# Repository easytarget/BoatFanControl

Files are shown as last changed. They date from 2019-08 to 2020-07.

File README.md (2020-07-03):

# Humidity and Temperature sensing fan controller for a small boat, with battery protector.
## By Owen.
#### My boat can get quite hot, suffers from condensation, and a permanent fan kept on flattening the battery.

A Small controller based on a Digispark ATTiny85 development board I have lying around and a spare DHT11 combined temperature and humidity sensor.
It turns the ventilator fan on and off (and several speeds in between) depending on the temperature, humidity, user input and battery state (voltage).

* [DigiSpark](https://digistump.com/wiki/digispark) Based
  * ATtiny85, plenty powerful enough for this application, and with a robust toolchain. It has 6 IO pins & very little extra cruft
  * Has a onboard 5v regulator, I can supply it with the battery voltage, and then power the DHT11 from the 5v line
  * Somewhat tricky to flash/develop for, Lack of a uart is a total pain during debug since BitBang serial emulators eat half the memory+
* DHT11 Temperature and Humidity sensor
  * Not the best sensor, something more accurate would be prefered, but this is what I have
  * A DHT22 would be an easy (plug and go) upgrade
* PWM fan control via a high-current logic-level NPN mosfet
  * I have a quiet but powerful (Noctuna) 12V PC case fan to run from this
* Battery voltage sensing for powersave and shutdown. My boat has a good battery and solar charging system, but the battery can still get low during use and late season.
* A button.. to allow on/off/quiet overrides, my bunk is 50cm from the fan and a quiet mode seems like a really good idea.

## Hardware
KiKad project files, Gerber files and the Case design files are all in this repository.

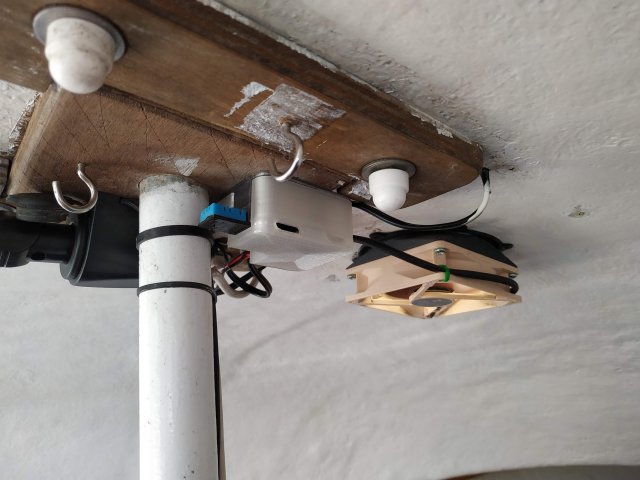
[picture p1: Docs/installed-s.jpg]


The circuit is very simple, there is a logic-level mosfet to drive the fan. I used a IRLZ14 for this but almost any logic-level mosfet will do, just make sure it can handle the *startup* current of your fan. If your fan is powerful you may need to add a heatsink to the mosfet and make sure heat from it does not affect the sensor.

The Digispark incorporates a 5V voltage regulator (LM7805), which only powers the ATTiny and the DHT11 sensor, the absolute maximum voltage this can handle is 35V, Digistump themselves recommend a maximum of 16V for the module. Please be careful when disconnecting batteries on boarts with solar/fixed charging systems, you may be able to spike the supply voltage enough to damage this. However; it is reasonably robust and may even work for a 24v systems, but no promises, and you will need to change the thresholds in the code ;-)

Here are some picture of my buildup; at this stage I had, *ahem*, forgotten to put a flyback diode in parallel to the fan. This could be a very bad idea if a high wind decides to spin the fan very fast. It is not visible in my pictures but I added a 1N4007 diode to the underside between the pins of the connector. The revised PCB now has this flyback diode onboard.

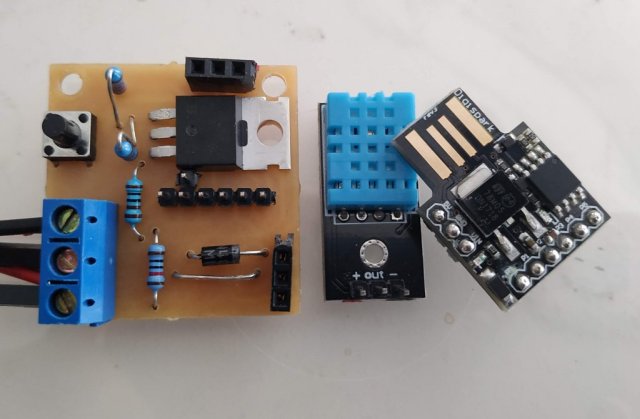
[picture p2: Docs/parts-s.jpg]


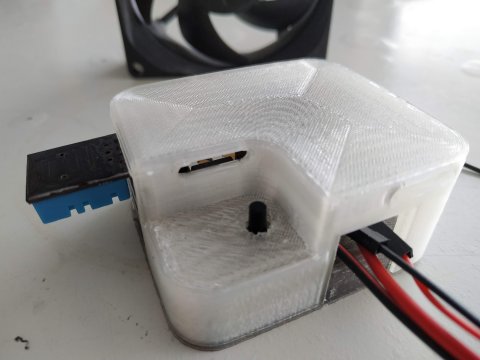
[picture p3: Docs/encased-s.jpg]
Ready To Fit
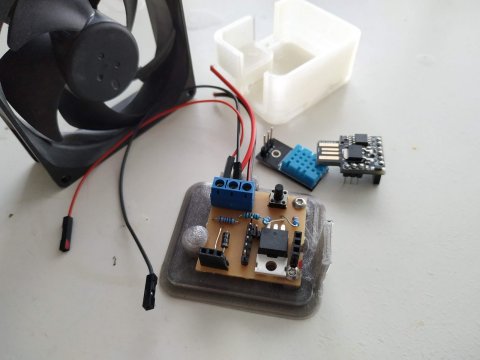
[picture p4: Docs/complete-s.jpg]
Proud
 

## Software
See the `BoatFanControl.ino` sketch in the `Software` folder. There are a number of other sketches in there that I used during development, you may find the `*Calibrate` scripts useful to verify your sensors and voltage divider.

The DigiStump boards definitions are [here](http://digistump.com/package_digistump_index.json), this needs to be added to the Boards URL list in the preferences dialog of the IDE. In the IDE, select `baoards -> Digistump AVR boards -> Digispark (16MHz, no USB)` for programming. The 'No USB' refers to clock speed alignment and is advised to keep the clock stable when not plugged into a USB port.

Please read the notes at the top of the main sketch, by default the Digispark runs the fan at 500Hz, this is possibly audible and might affect fan lifespan (the jury is out, I've seen people arguing both sides quite convincingly). In any case I decided to pump the [fan PWM frequency](https://digistump.com/wiki/digispark/tricks#how_to_increase_hardware_pwm_frequency) up as high as possible. But this requires modifying a file in the Digispark boards folder, proper details and URL's for reference are in the sketch header.

## Operation

* The controller takes a Temperature and Humidity reading every 20 seconds and then decides how to set fan based on the readings over the last 2 minutes.
* Power Control; the controller also reads the battery voltage and uses this to reduce battery drain when needed.
  * Vmin->11.8V : Powersave; no activity, but still wake every 20s to take and process a voltage reading. 
  * 11.8->12.5V : Low Power; fan is restricted to 33% power.
  * 12.5->Vmax  : Good Power; fan can rise to 100% power.
* Fan Control
  * The fan works on simple trigger values for temperature and humidity (28c and 70% respectively), the fan will start at 33% PWM power, and rise to 100% over the next four degrees temperature or 20% humidity. In low power mode the speed will never rise and remains at 30%
* Average readings; the last five readings are kept, the code discards any outliers before averaging the three middle values. This reduces any fast cycling and ignores the occasional 'way off' reading that DHT11's can occasionally produce (in my experience).
* User Control
  * The Button cycles: Full -> Quiet -> Off -> Full etc.. and the led flashes for feedback; two flashes for off, four for quiet and six for full.
  * Quiet mode is basically the same as Low power mode.
  * After three hours the User mode will change to the next higher power level, so that the button works more like a 3 hour 'sleep' function, it is not a on/off switch. I have an independently fused and switched line from my battery for this, and the mast head anchor light.
* The onboard LED flashes to indicate mode changes, errors, and when a sensor reading is made. It is dimmed in Quiet and Off modes.
  * If the unit continually flashes after startup then it is indicating a sensor disconnect or failure. 
  * During operation 10 very rapid flashes indicate a failed sensor reading.
* Testing is tricky due to lack of resources, serial debug is not practical due to memory and pin limitations. I found it best to test the sensors using the calibrate sketches. Then I ran on the testbench with much 'faster' timeouts (there is a option for this in the sketch), and my multimeters PWM (cycle and frequency) mode to check the output. I also used an identical sensor running on a Arduino Uno + a standard serial output DHT11 example to monitor the environment, and then spent time checking the results while breathing on sensors to trigger responses, and varying the voltage on my PSU.

## Low Power
If the battery is good and the fan is running then the power use is dominated by the fan (the mosfet is good to 6A).

But once the voltage drops to powersave levels it is desirable to have the controller draw minimal power to avoid flooring the battery.
* I use a low-power sleep mode between readings when the fan is off, this should reduce the load from the DigiSpark from a few milliamps to a few microamps. I dont have a meter sensitive enough to measure this with any accuracy.
* If you are serious about reducing power I also suggest replacing the R1/R2 (10K/1K) divider used for voltage sensing with a 470K/47K one, this reduces the power flow through them from 1.1 milliamps to 23 microamps at 12v.
* The DHT11 draws up to 2.5 milliamp when doing a reading and sending data, but should be under 100 microamps between readings. If I do a MK2 pcb I will power the DHT11 from the unused D4 pin (the ATtiny can supply enough power for this) and modify the code to switch it off between readings (nb: 250ms needed to recover when powered on).

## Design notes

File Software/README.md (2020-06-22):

# Code for the boat Fan Controller
Primary/complete code is in 'BoatFanControl' folder, please read the comments

The 'VoltageCalibrate' and 'SensorCalibrate' sketches are useful for verifying the hardware as well as checking calibration

Other folders contain test and/or experimental code I have played with

All code is for the DigiSpark board, ATTiny 85 based, and assumes the Arduino IDE is used

The tiny DHT11 sensor lib I use is from:
http://www.micro4you.com/files/sensor/
The files are included in the archive

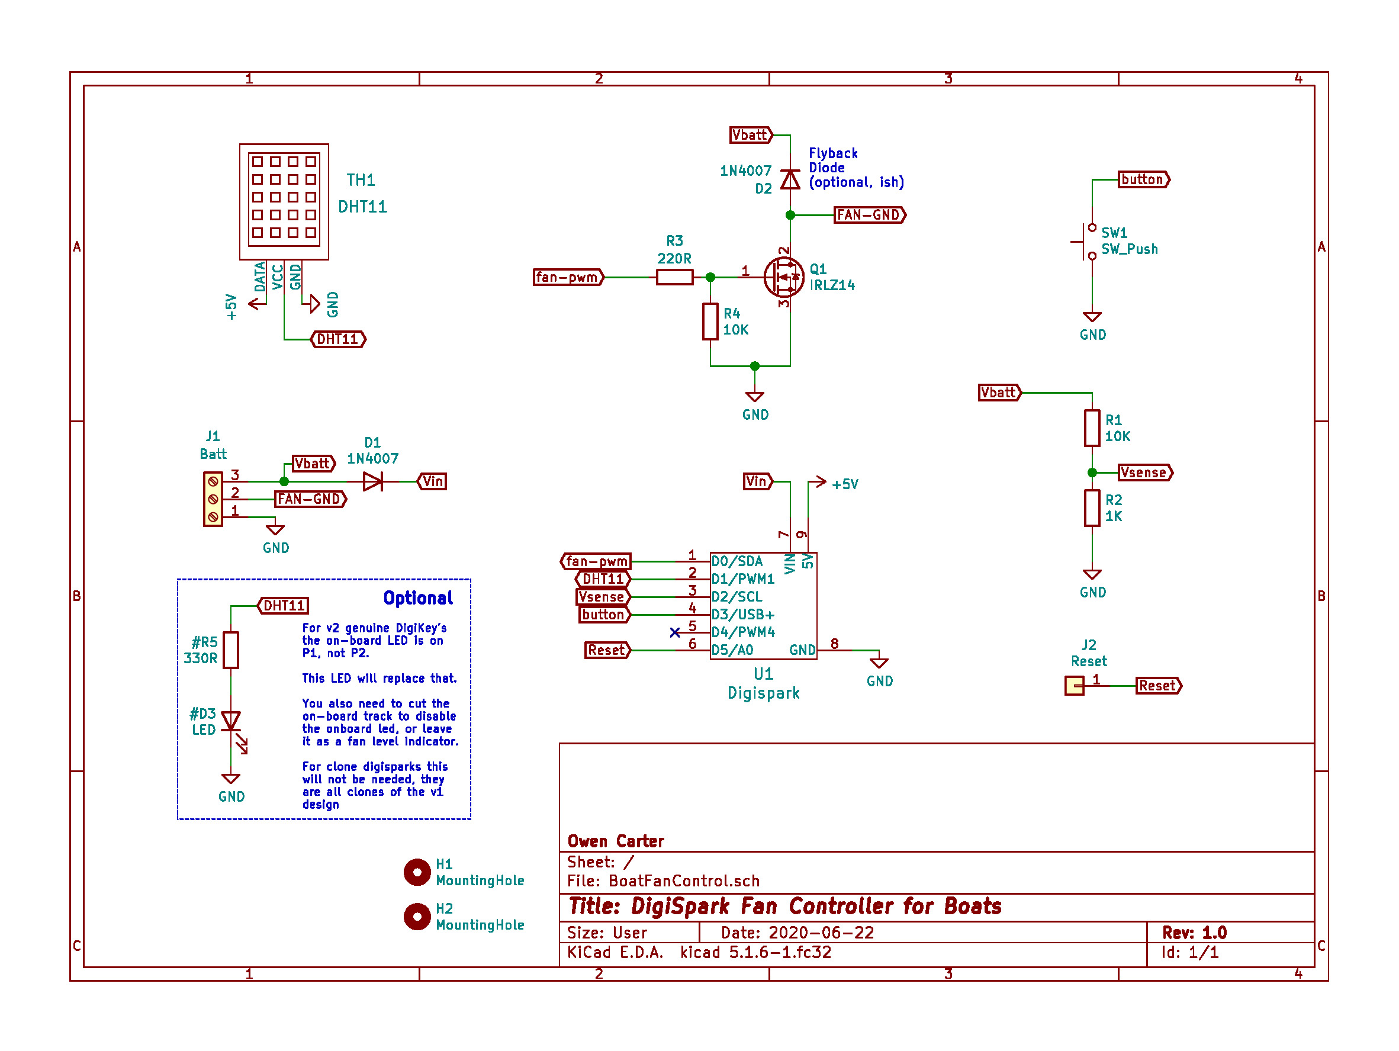
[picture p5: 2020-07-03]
Docs/Schematic.jpg

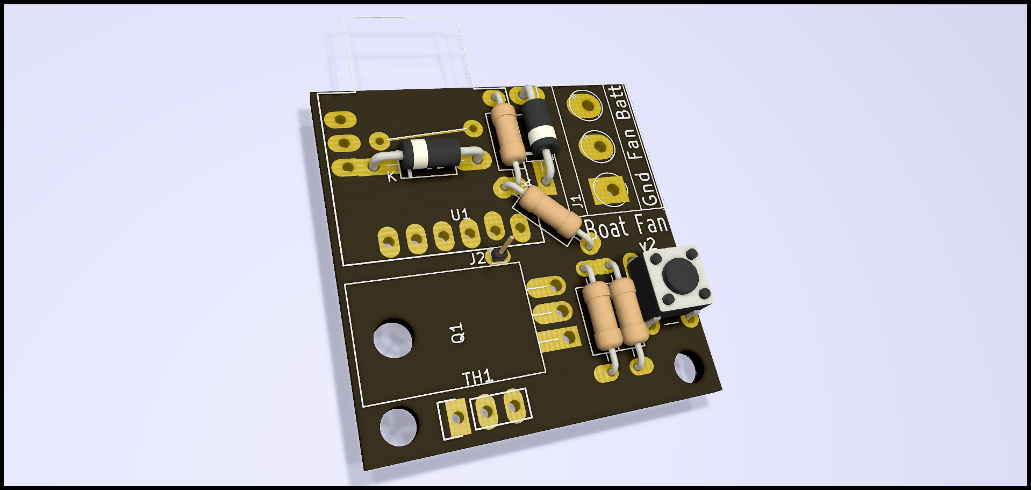
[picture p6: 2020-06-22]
Docs/BoatFanControlPCB.png

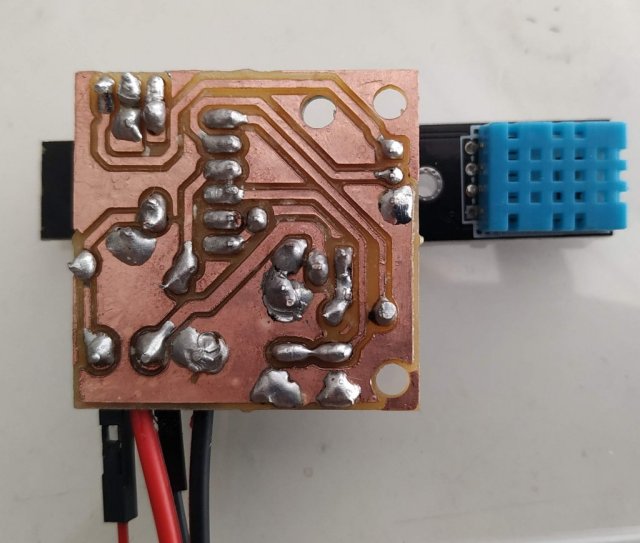
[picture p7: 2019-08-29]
Docs/pcb-s.jpg

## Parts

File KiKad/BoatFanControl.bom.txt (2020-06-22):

"Source:","/home/owen/Circuits/BoatFanControl/KiKad/BoatFanControl.sch"
"Date:","Mon 22 Jun 2020 17:11:08 CEST"
"Tool:","Eeschema 5.1.6-1.fc32"
"Generator:","/usr/share/kicad/plugins/bom_csv_grouped_by_value.py"
"Component Count:","14"

"Individual Components:"

"Item","Qty","Reference(s)","Value","LibPart","Footprint","Datasheet","Description","Manufacturer","Pricing"
"","","D1","1N4007","Diode:1N4007","Diode_THT:D_DO-41_SOD81_P10.16mm_Horizontal","http://www.vishay.com/docs/88503/1n4001.pdf","","",""
"","","D2","1N4007","Diode:1N4007","Diode_THT:D_DO-41_SOD81_P10.16mm_Horizontal","http://www.vishay.com/docs/88503/1n4001.pdf","","",""
"","","H1","MountingHole","Mechanical:MountingHole","MountingHole:MountingHole_3.2mm_M3","~","","",""
"","","H2","MountingHole","Mechanical:MountingHole","MountingHole:MountingHole_3.2mm_M3","~","","",""
"","","J1","Batt","Connector:Screw_Terminal_01x03","TerminalBlock_MetzConnect:TerminalBlock_MetzConnect_Type073_RT02603HBLU_1x03_P5.08mm_Horizontal","~","","",""
"","","J2","Reset","Connector_Generic:Conn_01x01","Connector_PinHeader_1.00mm:PinHeader_1x01_P1.00mm_Vertical","~","","",""
"","","Q1","IRLZ14","Transistor_FET:IRLIZ44N","Package_TO_SOT_THT:TO-220F-3_Horizontal_TabDown","http://www.irf.com/product-info/datasheets/data/irliz44n.pdf","","",""
"","","R1","10K","Device:R","Resistor_THT:R_Axial_DIN0207_L6.3mm_D2.5mm_P10.16mm_Horizontal","~","","",""
"","","R2","1K","Device:R","Resistor_THT:R_Axial_DIN0207_L6.3mm_D2.5mm_P10.16mm_Horizontal","~","","",""
"","","R3","220R","Device:R","Resistor_THT:R_Axial_DIN0207_L6.3mm_D2.5mm_P10.16mm_Horizontal","~","","",""
"","","R4","10K","Device:R","Resistor_THT:R_Axial_DIN0207_L6.3mm_D2.5mm_P10.16mm_Horizontal","~","","",""
"","","SW1","SW_Push","Switch:SW_Push","Button_Switch_THT:SW_PUSH_6mm","~","","",""
"","","TH1","DHT11","sensorz:DHT11_Temperature_Humidity","sensorz:DHT11_Temperature_Humidity","","","",""
"","","U1","Digispark","mcuz:Digispark","mcuz:Digispark","","Digispark Microcontroller","Digistump","0.00@0"

"Collated Components:"

"Item","Qty","Reference(s)","Value","LibPart","Footprint","Datasheet","Description","Manufacturer","Pricing"
"1","2","D1, D2","1N4007","Diode:1N4007","Diode_THT:D_DO-41_SOD81_P10.16mm_Horizontal","http://www.vishay.com/docs/88503/1n4001.pdf","","",""
"2","2","H1, H2","MountingHole","Mechanical:MountingHole","MountingHole:MountingHole_3.2mm_M3","~","","",""
"3","1","J1","Batt","Connector:Screw_Terminal_01x03","TerminalBlock_MetzConnect:TerminalBlock_MetzConnect_Type073_RT02603HBLU_1x03_P5.08mm_Horizontal","~","","",""
"4","1","J2","Reset","Connector_Generic:Conn_01x01","Connector_PinHeader_1.00mm:PinHeader_1x01_P1.00mm_Vertical","~","","",""
"5","1","Q1","IRLZ14","Transistor_FET:IRLIZ44N","Package_TO_SOT_THT:TO-220F-3_Horizontal_TabDown","http://www.irf.com/product-info/datasheets/data/irliz44n.pdf","","",""
"6","2","R1, R4","10K","Device:R","Resistor_THT:R_Axial_DIN0207_L6.3mm_D2.5mm_P10.16mm_Horizontal","~","","",""
"7","1","R2","1K","Device:R","Resistor_THT:R_Axial_DIN0207_L6.3mm_D2.5mm_P10.16mm_Horizontal","~","","",""
"8","1","R3","220R","Device:R","Resistor_THT:R_Axial_DIN0207_L6.3mm_D2.5mm_P10.16mm_Horizontal","~","","",""
"9","1","SW1","SW_Push","Switch:SW_Push","Button_Switch_THT:SW_PUSH_6mm","~","","",""
"10","1","TH1","DHT11","sensorz:DHT11_Temperature_Humidity","sensorz:DHT11_Temperature_Humidity","","","",""
"11","1","U1","Digispark","mcuz:Digispark","mcuz:Digispark","","Digispark Microcontroller","Digistump","0.00@0"

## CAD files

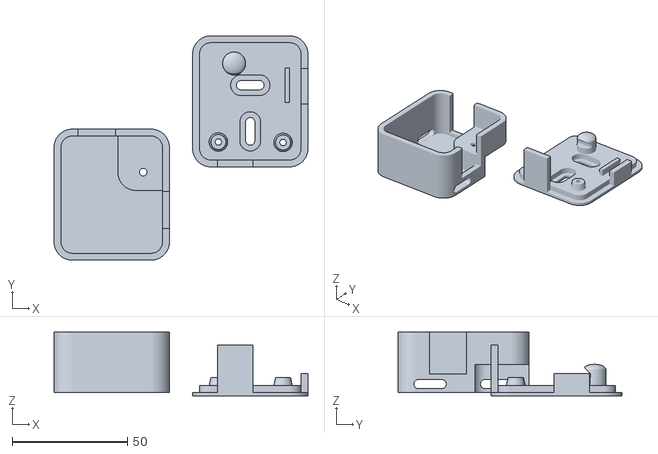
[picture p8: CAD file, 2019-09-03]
Case/case.stl
110.0 x 97.2 x 27.6

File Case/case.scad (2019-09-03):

// Case for Boat fan Controller
$fn=90; // slowish, but otherwise can look fugly.

// XY Zero is the same as PCB axis zero

fitting = !true;

// Some dimensions: (mm)

pcbCorners = [[-0.2,-0.2],
              [-0.2,34.6],
              [33.8,34.6],
              [33.8,-0.2]];
pcbHoles = [[3,2.6],
            [31,2.4]];    // <-- MY PCB ERROR
            //[31,2.6]];
pcbHoleDia = 3.7;
pcbThick = 1.6; // thickness
pcbBaseClear = 5; // clearance under pcb
pcbTopClear = 18; // Total height (with DSpark clearance)
pcbSideClear = 5; // clearance around pcb
pcbCenter = pcbCorners[0]+(pcbCorners[2]-pcbCorners[0])/2;

terminalPoly = [[24.8,19.16], 
                [31,19.16],
                [31,34.4],
                [24.8,34.4]];
terminalCablePoly = [terminalPoly[0], // extended for case holes
                     terminalPoly[1]+[20,0],
                     terminalPoly[2]+[20,0],
                     terminalPoly[3]];
terminalCutoutMargin = [0,0.4];
terminalCutoutPoly = [terminalCablePoly[0]-terminalCutoutMargin,
                     terminalCablePoly[1]-terminalCutoutMargin,
                     terminalCablePoly[2]+terminalCutoutMargin,
                     terminalCablePoly[3]+terminalCutoutMargin];
terminalHigh = 10; 

dSparkExtra = 6; // extra Y axis clearance for DSpark usb pin
dSparkLift = 12;  // Clearance from main pcb
dSparkThick = 2.5;  // DigiSpark board thickness
dSparkPoly = [[0.45,16.85],
              [19.45,16.85],
              [19.45,34.35],
              [16.02,34.35],
              [16.02,43.35],
              [3.99,43.35],
              [3.99,34.35],
              [0.45,34.35]];
              
dht11Lift = 12.5; // Clearance from main pcb
dht11Thick = 1.6; // DHT11 pcb thickness
dht11Poly = [[2.5,4.5], // Really!!
             [18,4.5],
             [18,-28],
             [2.5,-28]];
dht11CutoutMargin = [0.4,0] ; // Make a case cutouts.
dht11CutoutPoly = [dht11Poly[0]-dht11CutoutMargin, 
                   dht11Poly[1]+dht11CutoutMargin, 
                   dht11Poly[2]+dht11CutoutMargin,
                   dht11Poly[3]-dht11CutoutMargin];

caseThick = 3; // case wall thickness
caseCorners = [pcbCorners[0],
               pcbCorners[1]+[0,dSparkExtra],
               pcbCorners[2]+[0,dSparkExtra],
               pcbCorners[3]];

buttonPos = [30.45,10.45]; // ??? position on pcb <- accurate???
buttonBase = 4; // height of the base
buttonPinDia = 3.2; // button pin+clearance
buttonPinHigh = 9.1; // b////utton pin top above pcb
buttonPoly = [buttonPos+[-3,-20],
              buttonPos+[-3,0],
              buttonPos+[10,0],
              buttonPos+[10,-20]];


module lid() 
difference () {
    union() {
        // A solid lid
        translate([0,0,caseThick/2+pcbBaseClear+pcbThick+pcbTopClear])
        linear_extrude(height=caseThick/2,convexity=10)
        minkowski() {
            polygon(caseCorners);
            circle(pcbSideClear+caseThick);
        }
        // Walls
        translate([0,0,caseThick/2])
        linear_extrude(height=pcbBaseClear+pcbThick+pcbTopClear,convexity=10)
        walls();
        // Button plate
        translate([0,0,caseThick+pcbBaseClear+pcbThick+buttonBase+0.5])
        linear_extrude(height=caseThick/2,convexity=10)
        intersection() {
            minkowski() {
                polygon(buttonPoly);
                circle(pcbSideClear+caseThick);         
            }
            minkowski() {
                polygon(caseCorners);
                circle(pcbSideClear);
            }
        }
        // Button Plate Walls
        translate([0,0,caseThick*1.5+pcbBaseClear+pcbThick+buttonBase+0.5])
        linear_extrude(height=pcbTopClear-caseThick-buttonBase+0.5,convexity=10)
        difference() {
            intersection() {
                minkowski() {
                    polygon(buttonPoly);
                    circle(pcbSideClear+caseThick);
                }
                minkowski() {
                    polygon(caseCorners);
                    circle(pcbSideClear+caseThick);
                }
            }
            minkowski() {
                polygon(buttonPoly);
                circle(pcbSideClear);         
            }
        }
    }
    // Slots for dht11 and cables
    linear_extrude(height=caseThick+pcbBaseClear+pcbThick+dht11Lift+dht11Thick+0.4, convexity=10)
    intersection() {
        walls();
        polygon(dht11CutoutPoly);
    }
    linear_extrude(height=caseThick+pcbBaseClear+pcbThick+terminalHigh, convexity=10)
    intersection() {
        walls();
        polygon(terminalCutoutPoly);
    }
    // Button Cutout.
    translate([0,0,1.5*caseThick+pcbBaseClear+pcbThick+buttonBase+0.5])
    linear_extrude(height=30,convexity=10) {
        minkowski() {
            polygon(buttonPoly);
            circle(pcbSideClear);         
        }
    }
    // Button pin
    translate(buttonPos)
    cylinder(d=buttonPinDia+0.1,h=2*pcbTopClear);
    // Cooling Holes
    translate(caseCorners[0]+[0,6])
    translate([0,0,caseThick*2+pcbTopClear])
    rotate([0,-90,0])
    hull() {
        translate([0,-5,0])
        cylinder(r=2,h=100,center=true);
        translate([0,5,0])
        cylinder(r=2,h=100,center=true);
    }
    translate(caseCorners[1]-[0,6])
    translate([0,0,caseThick*2+pcbTopClear])
    rotate([0,-90,0])
    hull() {
        translate([0,-5,0])
        cylinder(r=2,h=100,center=true);
        translate([0,5,0])
        cylinder(r=2,h=100,center=true);
    }
}

// Base
module base() {
    // Shell
    difference() {
        // Plate
        union() {
            linear_extrude(height=caseThick/2)
            difference() {
                minkowski() {
                    polygon(caseCorners);
                    circle(pcbSideClear+caseThick);
                }
                mountholes(4);
            }
            linear_extrude(height=caseThick*1.5)
            difference() {
                minkowski() {
                    polygon(caseCorners);
                    circle(pcbSideClear);
                }
                mountholes(9);
            }
        }
    }
    // PCB Screw Mounts
    for (a=[0,1]) {
        translate(pcbHoles[a]) 
        difference() {
            cylinder(d1=10,d2=6.5,h=caseThick+pcbBaseClear);
            cylinder(d=pcbHoleDia/1.2,h=caseThick+pcbBaseClear+1,$fn=6);
        }
    }
    // PCB Clip
    translate(pcbCorners[1]+[10,2])
    difference() {
        hull() {
            cylinder(d=10,h=1);
            translate([0,0,caseThick+2*pcbThick+pcbBaseClear])
            scale([1,1,0.5])
            sphere(d=10);
        }
        translate([-10,-11.8,caseThick+pcbBaseClear-0.1])
        hull() {
            cube([20,10,pcbThick+0.1]);
            translate([0,-10,10])
            cube([20,10,pcbThick]);
        }
    }
    // ScrewTerminal Support
    translate(pcbCorners[2])
    translate([-2,-15,caseThick])
    cube([2,15,pcbBaseClear]);
    // Fill Plates
    linear_extrude(height=caseThick+pcbBaseClear+pcbThick+dht11Lift, convexity=10)
    intersection() {
        walls();
        polygon(dht11Poly);
    }
    linear_extrude(height=caseThick+pcbBaseClear+pcbThick, convexity=10)
    intersection() {
        walls();
        polygon(terminalCablePoly);
    }
        
}

module walls() {
    // The walls of the case
    difference() {
        minkowski() {
            polygon(caseCorners);
            circle(pcbSideClear+caseThick);
        }
        minkowski() {
            polygon(caseCorners);
            circle(pcbSideClear);
        }
    }
}

module mountholes(slotdia=4) {
    // Mounting Holes
    translate(pcbHoles[0]) circle(d=pcbHoleDia);
    translate(pcbHoles[1]) circle(d=pcbHoleDia);
    hull() {
        translate(pcbCenter+[-4,10]) circle(d=slotdia);
        translate(pcbCenter+[4,10]) circle(d=slotdia);
    }
    hull() {
        translate(pcbCenter+[0,-14]) circle(d=slotdia);
        translate(pcbCenter+[0,-6]) circle(d=slotdia);
    }
}

// PCBs for fitting
module pcbs() if (fitting) color("lightgreen", 0.4) {
    // pcb
    translate([0,0,caseThick+pcbBaseClear])
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

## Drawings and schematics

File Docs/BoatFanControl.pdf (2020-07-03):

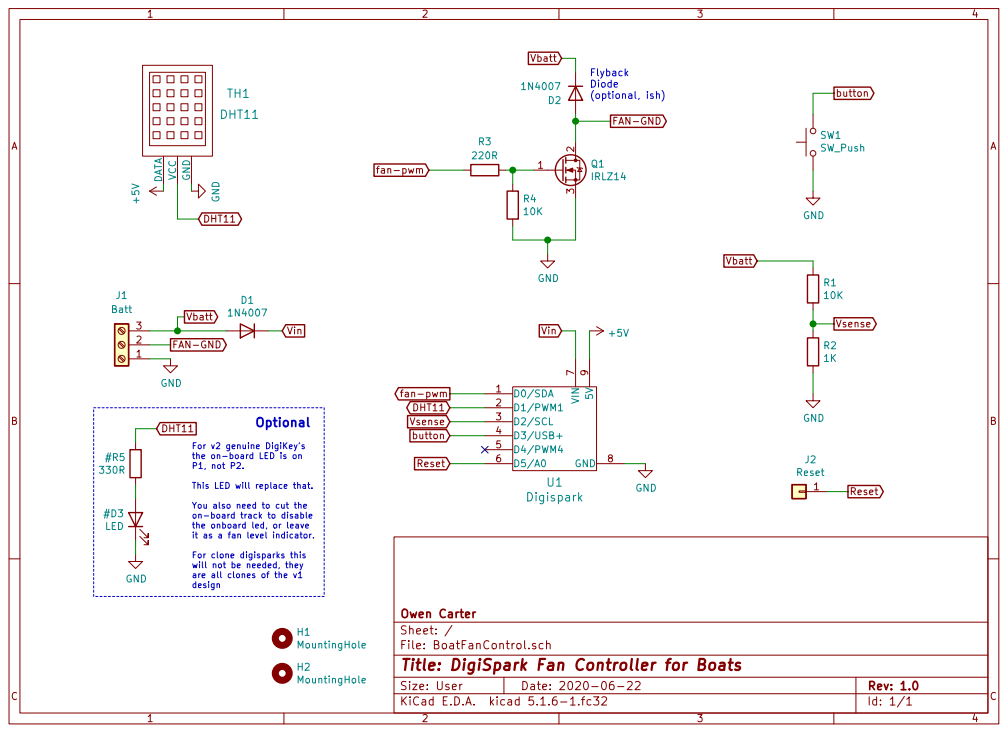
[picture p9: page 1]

Flyback Diode (optional, ish)

File: BoatFanControl.sch Sheet: / Owen Carter +5V

For v2 genuine DigiKey's
the on-board LED is on P1, not P2. This LED will replace that. You also need to cut the on-board track to disable

the onboard led, or leave

Id: 1/1 Title: DigiSpark Fan Controller for Boats

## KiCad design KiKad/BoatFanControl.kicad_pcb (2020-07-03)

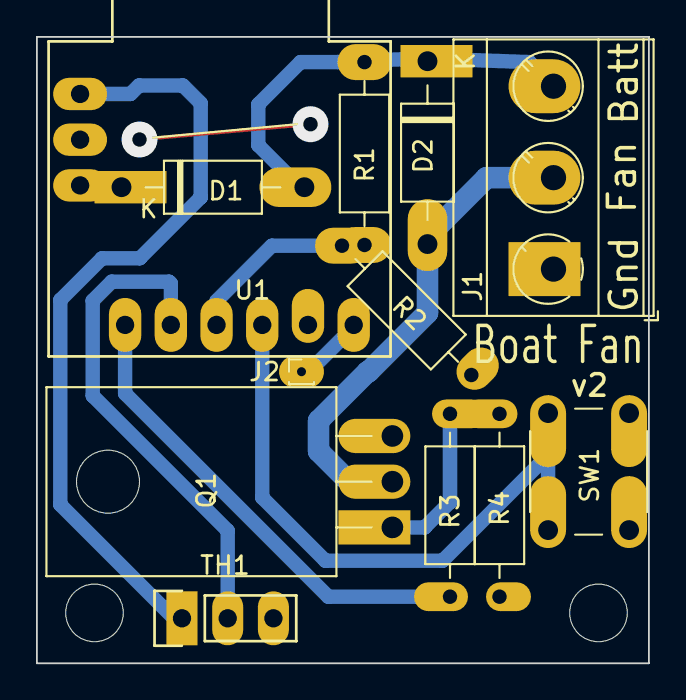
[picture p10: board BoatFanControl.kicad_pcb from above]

Board: 2 copper layers, 34.0 x 34.8 mm, 14 parts (0 on the bottom side), 11 nets.

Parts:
D1, D2: 1N4007; D_DO-41_SOD81_P10.16mm_Horizontal
H1, H2: MountingHole; MountingHole_3.2mm_M3
J1: Batt; TerminalBlock_MetzConnect_Type073_RT02603HBLU_1x03_P5.08mm_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
J2: Reset; PinHeader_1x01_P1.00mm_Vertical
Q1: IRLZ14; TO-220F-3_Horizontal_TabDown
R1, R4: 10K; R_Axial_DIN0207_L6.3mm_D2.5mm_P10.16mm_Horizontal
R2: 1K; R_Axial_DIN0207_L6.3mm_D2.5mm_P10.16mm_Horizontal
R3: 220R; R_Axial_DIN0207_L6.3mm_D2.5mm_P10.16mm_Horizontal
SW1: SW_Push; SW_PUSH_6mm
TH1: DHT11; DHT11_Temperature_Humidity
U1: Digispark

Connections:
+5V: TH1.1, U1.9
DHT11: TH1.2, U1.2
FAN-GND: D2.2, J1.2, Q1.2
GND: J1.1, Q1.3, R2.2, R4.2, SW1.1, TH1.3, U1.8
unnamed: Q1.1, R3.2, R4.1
Reset: J2.1, U1.6
Vbatt: D1.2, D2.1, J1.3, R1.1
Vin: D1.1, U1.7
Vsense: R1.2, R2.1, U1.3
button: SW1.2, U1.4
fan-pwm: R3.1, U1.1

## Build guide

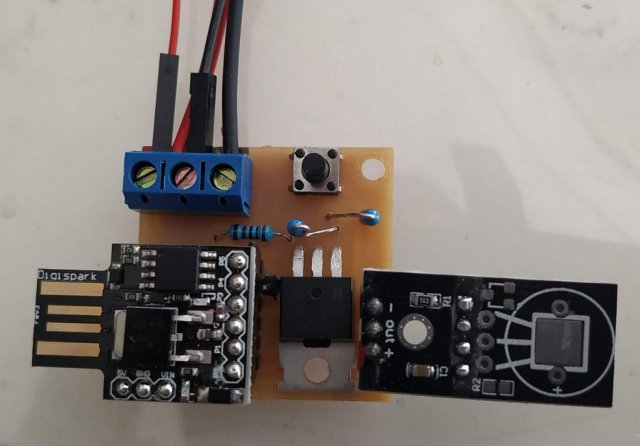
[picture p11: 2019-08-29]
Docs/assembled-s.jpg

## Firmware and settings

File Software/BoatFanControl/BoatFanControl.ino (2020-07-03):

 /* boat fan control

 Reads DHT11 Temperature and Humidity plus the battery Voltage
 It uses these values to set the PWM fan appropriately while supporting
 automatic and user triggered powersave and off modes 

         D5 - Reset pin
         D4 - N/C       (USB-)
  Digi   D3 - Button    (USB-)
  spark  D2 - Vin Sense
         D1 - DHT11     (Onboard LED)
         D0 - Fan PWM

 Notes: 
  DHT11 is pretty low accuracy and only returns whole integer results.
  See definitions below on how to calculate voltage trigger levels.

  The default PWM frequency is 500Hz; this can be audible on the fan.
  Running a DigiSpark at higher PWM frequency is (relatively) easy but
  does involve modifying the wiring.c header file (in the digispark board
  toolchain).
  See: https://digistump.com/wiki/digispark/tricks#how_to_increase_hardware_pwm_frequency

  In my case I had to edit 
  ~/.arduino15/packages/digistump/hardware/avr/1.6.7/cores/tiny/wiring.c
  - this is on linux, on Windows this should be somewhere like:
  C:\Users\<MyUserName>\AppData\Local\Arduino15\packages\digistump\hardware\avr\1.6.7\cores\tiny

  I followed the guide and set MS_TIMER_TICK_EVERY_X_CYCLES to 1 and the PWM frequency was
  now very high (32KHz), but the millis() timer ran at half speed. Grrr, timer0 issues.

  A very easy fix turns out to be programming the DigiSpark at 16MHz (fixed)
  frequency instead of the default USB sycnched clock setting of 16.5MHz.
  Changing the board to 'Board -> Digistump AVR Boards -> Digispark (16MHz, no USB)'
  restored the millis() timer to correct operation while retaining the fast PWM.
  NB: This fix must be re-applied in the (unlikely) event of the DigiStump 
  boards package being updated.

*/

// Run with faster cycles and with different voltage triggers on my testbench 
//#define BENCH

#include <avr/sleep.h>
#include <avr/wdt.h>
#include "DHT11.h"

// Utility macros
#define adc_disable() (ADCSRA &= ~(1 << ADEN))
#define adc_enable()  (ADCSRA |= (1 << ADEN))

// Pins
#define FAN_PIN 0
#define DHT_PIN 1
#define VIN_PIN 2
#define VIN_APIN 1 // digital pin 2 is also analog pin 1
#define BUTTON_PIN 3
#define BTNINT PCINT3

// Values
#define FAN_OFF    0
#define FAN_LOW   95
#define FAN_HIGH 255
#define LED_OFF    0
#define LED_LOW   10
#define LED_HIGH 255

/* 
   The ADC reading is multiplied by a scale factor = (5/1024)*11 = 0.05371 to get Volts
   The 0-5v ADC range returns a 10 bit reading of VIN via a 10k:1k resistor divider
   Value used here was double-checked by calibration.
   Use the following when calculating VIN_LOW & VIN_GOOD
   VOLTAGESCALE = 0.0531 
*/

// Limits
#define VIN_LOW  222  // turn on only when above 11.8v (integer) = 11.8 / VOLTAGESCALE
#define VIN_GOOD 235  // run full when above 12.5v (integer) = 12.5 / VOLTAGESCALE
#define TEMP_TRIGGER 28   // turn fan on when above this temperature (integer)
#define HUMI_TRIGGER 70   // turn fan on when above this humidity (integer)

// In high power mode the fan PWM rises from FAN_LOW by this value for each integer
//  above TEMP_TRIGGER or HUMI_TRIGGER respectively (until constrained by FAN_HIGH).
#define TEMP_RISE 40   // = (FAN_HIGH - FAN_LOW) / 4
#define HUMI_RISE 8    // = (FAN_HIGH - FAN_LOW) / 20

// During sleep the millis() counter is stopped, so
//  we take timings for the reading and resume cycles
//  by counting watchdog cycles.

//   watchdog period:: 0=16ms, 1=32ms,2=64ms,3=128ms,
//   4=250ms, 5=500ms, 6=1s,7=2s, 8=4s, 9= 8s
#define WDPERIOD 8        // Sleep cycle = 4 seconds
#define READCYCLES 5       // Reading cycles:   5x4s = 20s
#define RESUMECYCLES 2700  // Resume cycles: 2700x4s = 3hrs


#ifdef BENCH  // apply some overrides for testing on the bench
  #undef READCYCLES
  #define READCYCLES     2    // 8s
  #undef RESUMECYCLES
  #define RESUMECYCLES  30  //  2mins
#endif

// Sensor
DHT11 dht;

// Last 5 readings are retained
byte t[5];
byte h[5];
unsigned int v[5];

// Power mode. Defaults to high, then cycles ->off->low->high etc with button
enum powerstates{off,low,high} power = high;

// UI and watchdog
int sensorcounter = READCYCLES;  // counts watchdog to trigger readings, preloaded
int resumecounter = 0;  // counts watchdog events for mode resume
bool watchdog = false;  // flag when watchdog triggered
bool button = false;    // flag when button pressed
int index = 0;          // Index to the readings array
byte fan = 0;           // Current fan setting
byte led = 255;         // LED Power (reduced in quiet/off modes)

/* Utility Functions */

void flashFast(byte flashes, byte pwm)
{
  pinMode(DHT_PIN, OUTPUT);
  for (byte i=0; i < flashes; i++) {
    analogWrite(DHT_PIN,pwm);
    delay(80);
    digitalWrite(DHT_PIN,LOW);
    delay(150);
  }
}

/* Sleep Functions */

void setup_watchdog(int period) {
  byte bitbuf;
  if (period > 9 ) period=9;
  bitbuf=period & 7;
  if (period > 7) bitbuf|= (1<<5);
  bitbuf|= (1<<WDCE);
  MCUSR &= ~(1<<WDRF);
  // start timed sequence
  WDTCR |= (1<<WDCE) | (1<<WDE);
  // set new watchdog timeout value
  WDTCR = bitbuf;
  WDTCR |= _BV(WDIE);
}

void setup_pininterrupt() {
  GIMSK |= _BV(PCIE);
  PCMSK |= _BV(BTNINT);
}

// Watchdog Interrupt Service 
ISR(WDT_vect) {
  watchdog = true;
  sensorcounter++;
  if (resumecounter < RESUMECYCLES) resumecounter++;
}

// Pin interrupt service
ISR(PCINT0_vect) {
  // ignore unless pin is low
  if (!digitalRead(BUTTON_PIN)) button=true;
}

/*   SETUP    */

void setup() 
{
  pinMode(VIN_PIN,INPUT);
  pinMode(BUTTON_PIN,INPUT_PULLUP);
  pinMode(FAN_PIN,OUTPUT);
  analogWrite(FAN_PIN,0);
  dht.setup(DHT_PIN);

  // pre-populate the results
  do {
    flashFast(3,LED_HIGH);
    delay(250);
    pinMode(DHT_PIN, INPUT);  // set to input for dht readings
    delay(250);
    t[0] = constrain(dht.getTemperature(),0,40);
    h[0] = constrain(dht.getHumidity(),0,100);
    v[0] = constrain(analogRead(VIN_APIN),0,350);
  } while (strcmp(dht.getStatusString(),"OK") != 0);
  for (byte i=1; i < 5; i++) {  
    t[i] = t[0];
    h[i] = h[0];
    v[i] = v[0];
  }

  // Set up interrupts
  setup_watchdog(WDPERIOD);
  setup_pininterrupt();
}

/*   LOOP     */

void loop() {
  button=false;

  adc_disable();   // switch ADC off while asleep
  while ((sensorcounter < READCYCLES) && !button) {
    // Loop here accumulating interrupts until button is pressed or
    //  the watchdog counter reaches READCYCLES
    if (fan > FAN_OFF) {
      // if fan is running, we are in a battery ok state
      // Use delay(); we cant sleep since that shuts PWM down
      while (!button && !watchdog) delay(50); 
    } 
    else {
      // fan is off, use a sleep mode
      set_sleep_mode(SLEEP_MODE_PWR_DOWN);
      sleep_enable();
      sleep_mode();    // Sleep here
      sleep_disable(); 
    }
    if (button) {
      delay(20);    // debounce
      if (!digitalRead(BUTTON_PIN)) button = true;
      else button = false;
    }
    if (watchdog) {     // Timed out watchdog
      watchdog=false;   // reset flag, counter is incremented in service routine.
    }
  }
  sensorcounter = 0; // reset the counter
  adc_enable();   // switch ADC back on
  analogRead(VIN_APIN);  // stabilise ADC, 1st reading after resume is unreliable
  
  // auto change from off->low->full power according to resume counter
  if ((power != high) && (resumecounter == RESUMECYCLES)) {
    button = true;  // virtual button press to change state ;-)
    resumecounter = 0; // reset the counter
  }

  // Process button
  if (button) {
    switch (power)  // Change power modes
    {
      case off:  power = low; 
                 flashFast(4,LED_HIGH);
                 led = LED_LOW;
                 break;
      case low:  power = high; 
                 flashFast(6,LED_HIGH);
                 led = LED_HIGH;
                 break;
      case high: power = off;
                 flashFast(2,LED_HIGH);
                 led = LED_OFF; 
                 break;
    }
    resumecounter = 0;
  }

  // Readings
  pinMode(DHT_PIN, INPUT);  // set to input for the dht readings
  delay(1); // let pin settle

  // take readings and constrain to sensible value range
  byte temp = constrain(dht.getTemperature(),0,40);
  byte humi = constrain(dht.getHumidity(),0,100);
  float volt = constrain(analogRead(VIN_APIN),100,350);
  if (strcmp(dht.getStatusString(),"OK") != 0) 
  {
    // Reading error; flash led 10 times
    flashFast(10,max(led,LED_LOW));
  } 
  else
  {
    // Good reading; save it
    index++;
    index%=5;
    t[index] = temp;
    h[index] = humi;
    v[index] = volt;
  }

  pinMode(DHT_PIN, OUTPUT); // flash led after reading
  analogWrite(DHT_PIN,led);
  delay(10);
  if (power == low) delay(100);
  if (power == high) delay(200);
  digitalWrite(DHT_PIN,LOW);

  // Averages
  unsigned int ttot=0, tmax=0, tmin=255;
  unsigned int htot=0, hmax=0, hmin=255;
  unsigned int vtot=0, vmax=0, vmin=65534;
  for (byte i=0; i < 5; i++)    // last 5 readings are retained
  {
    ttot+=t[i];                  // Calculate totals while
    if (t[i] < tmin) tmin=t[i];  //  noting the highest/lowest values
    if (t[i] > tmax) tmax=t[i];
    htot+=h[i];
    if (h[i] < hmin) hmin=h[i];
    if (h[i] > hmax) hmax=h[i];
    vtot+=v[i];
    if (v[i] < vmin) vmin=v[i];
    if (v[i] > vmax) vmax=v[i];
  }
  ttot = ttot - tmax - tmin;   // take off min and max values from the totals
  htot = htot - hmax - hmin;
  vtot = vtot - vmax - vmin;
  unsigned int tempAvg = round(float(ttot) / 3);  // then divide by 3
  unsigned int humiAvg = round(float(htot) / 3);  // note: we force a floating point 
  unsigned int voltAvg = round(float(vtot) / 3);  //  calculation so rounding works
 
  // Process values and decide on fan settings
  if ((voltAvg < VIN_LOW) || (power == off))
  {
    // Low battery: turn off.
    fan = FAN_OFF;
  }
  else if ((voltAvg < VIN_GOOD) || (power == low))
  {
    // Poor battery: set fan to low speed based on temp+humidity
    if ((tempAvg > TEMP_TRIGGER) || (humiAvg > HUMI_TRIGGER)) 
    {
      fan = FAN_LOW;
    } else {
      fan = FAN_OFF;
    }
  }
  else 
  {
    // Good battery: set fan proportionally above FAN_LOW based on temp+humidity
    // Constrain result to never exceed FAN_HIGH
    unsigned int fanT = 0;
    unsigned int fanH = 0;
    if (tempAvg >= TEMP_TRIGGER)
    {
      fanT = min(FAN_LOW + ((tempAvg - TEMP_TRIGGER) * TEMP_RISE),FAN_HIGH); 
    }
    if (humiAvg >= HUMI_TRIGGER) 
    {
      fanH = min(FAN_LOW + ((humiAvg - HUMI_TRIGGER) * HUMI_RISE),FAN_HIGH);
    }
    fan = max(fanT,fanH); 
  }

  // This is why we do all the above.. ;-)
  analogWrite(FAN_PIN,fan);

}

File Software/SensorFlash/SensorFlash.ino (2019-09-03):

// ShowSensorData
//
// Reads DHT11 temperature and humidity and Voltage on 
// the BoatFanController, and flashes a LED on the fan pin to
// show the readings

#include <DHT11.h>
DHT11 dht;

#define FAN_PIN 0
#define DHT_PIN 1
#define VCC_PIN 2
#define VCC_APIN 1 // digital pin 2 == Analog pin 1
#define BUTTON_PIN 3 

// Defaults for flash sequences.
const int flashOn = 150;
const int flashOff = 200;
const int flashErr = 40;
const int flashZero = 500; // long flash for zereo
const int digitDelay = 1000; // delay between digits
const int valueDelay = 2000; // delay after sending



float readVbatt() 
{
  // Take ADC reading and multiply by a scale factor = (5/1024)*11 = 0.05371
  // From: 0-5v ADC 10 bit reading, and 10k:1k resistor divider
  // Practical value used here is above + (tiny) calibration.

  int res = analogRead(VCC_APIN);
  return res * 0.053; // Vbatt in volts
}


void flashValue(int val)
// assumes val is an integer between 0 - 99 
{
  int valT = val / 10;
  int valU = val - (valT * 10);
  flashFan(valT);
  delay(digitDelay);
  flashFan(valU);
  delay(valueDelay);
}

void flashFan(int digit)
{
  if (digit == 0) // long flash for a Zero
  {
    analogWrite(FAN_PIN,255);
    delay(flashZero);
    analogWrite(FAN_PIN,0);
    delay(flashOff);
  }
  else // N quick flashes for a value
  {
    for (int i = 0; i < digit; i++)
    {
      analogWrite(FAN_PIN,255);
      delay(flashOn);
      analogWrite(FAN_PIN,0);
      delay(flashOff);
    }
  }
}

/*   SETUP    */

void setup() {
  // Set HiSpeed PWM. Does it screw up delay and dht11?
  TCCR0B = TCCR0B & 0b11111000 | 0b001;

  pinMode(FAN_PIN,OUTPUT);
  analogWrite(FAN_PIN,0);
  dht.setup(DHT_PIN);
  pinMode(VCC_PIN,INPUT);
  pinMode(BUTTON_PIN,INPUT);
}

/*   LOOP     */

void loop() {
  
  int temp = dht.getTemperature();
  int humi = dht.getHumidity();

  if (strcmp(dht.getStatusString(),"OK") != 0) 
  {
    // Not a valid result.. v.rapid flash for a a few secs.
    for (int i = 0; i < 40; i++) 
    {
      analogWrite(FAN_PIN,255);
      delay(flashErr);
      analogWrite(FAN_PIN,0);
      delay(flashErr);
    }
    delay(valueDelay);
  }
  else 
  {
    // DHT pin is also the notofication led pin..
    pinMode(DHT_PIN, OUTPUT);
    digitalWrite(DHT_PIN, LOW);
    // the DHT lib will leave it as an input..
    
    // Flash out values when button pressed

    // Temperature
    flashValue(temp);

    // Humidity
    flashValue(humi);
    
    // Voltage
    int vbatt = readVbatt() * 10;
    int vbattH = vbatt / 100;
    int vbattT = (vbatt - (vbattH * 100)) / 10;
    int vbattU = (vbatt - (vbattH * 100) - (vbattT * 10));
    flashFan(vbattH);
    delay(digitDelay);
    flashFan(vbattT);
    delay(digitDelay);delay(digitDelay); // decimal point
    flashFan(vbattU);
    delay(valueDelay);
  } 
 
  // wait for a button press (button is inverted)
  delay(1000); // 2sec delay
  byte pwm = 255;
  while (( digitalRead(BUTTON_PIN) == true ) && ( pwm != 0 )) {
    analogWrite(FAN_PIN,pwm);
    pwm--;
    delay(100);
  }
  while (( digitalRead(BUTTON_PIN) == true) && ( pwm != 255 )) {
    analogWrite(FAN_PIN,pwm);
    pwm++;
    delay(100);
  }
  digitalWrite(DHT_PIN, HIGH);
  delay(30); // debounce delay
  while (digitalRead(BUTTON_PIN) == false) delay(10); // wait for release
  analogWrite(FAN_PIN,0); // turn led off
  delay(330);
  digitalWrite(DHT_PIN, LOW); 
}

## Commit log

2019-08-27 Initial; circuit done, based off of the solar light controller
    [BoatFanControl.kicad_pcb, BoatFanControl.sch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]
2019-08-28 Updated with seperate DHT11 mount
    [BoatFanControl.kicad_pcb, BoatFanControl.sch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]
2019-08-29 Some documentation
    [BoatFanControl.sch]
2019-08-30 Case, make PCB square..
    [BoatFanControl.kicad_pcb, case.scad, case.stl]
2019-09-03 High speed PWM and led control
2019-09-03 Case Mods
    [case.scad, case.stl]
2019-09-18 Add some demos so I can work on Interrupt routines
2019-09-30 Get the interrupt demos workimg
2019-09-30 Work on interrupt and test code
2020-06-07 switch to DigiUSB for debug
2020-06-07 DigiUSB debug works, sensor often fails
    [BoatFanControl.ino]
2020-06-08 Checkpoint, working voltage calibrator
2020-06-08 Working test and calibration programs usinf DigiUSB for comms
2020-06-09 Nicely working sensor calibrator and tester, using DigiUSB
2020-06-12 button wrangler part 1
2020-06-12 Very close to final; needs proportional fan in high mode
2020-06-18 Refactor following release; this will be r1.1
    [BoatFanControl.kicad_pcb, BoatFanControl.sch, case.scad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]
2020-06-22 PCB work, add flyback diode
    [BoatFanControl.kicad_pcb, BoatFanControl.sch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]
2020-06-22 New schematic
2020-06-26 New combined interrupt demo. Works!
2020-06-26 Starting on interrupt sleep between reaings, lower power consumption ehen fan off Debug/DigiUSB has been stripped out, no longer necesscary Sleep setup routines are imported. Still need implementing 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
    [BoatFanControl.ino]
2020-06-29 Test of how to run main loop using interrupts
2020-07-01 Sleep mode in between readings when fan is off, lower power
2020-07-03 Refresh the PCB
    [BoatFanControl.kicad_pcb, BoatFanControl.sch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]
